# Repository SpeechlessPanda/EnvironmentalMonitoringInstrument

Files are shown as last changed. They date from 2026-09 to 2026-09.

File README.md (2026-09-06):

<div align="center">

# 环境监测仪

哈尔滨工业大学（深圳）电子工艺实习 · 题号 E1

**优秀项目** — 由任课教师评选的课程荣誉

手持环境监测仪：MSPM0G3507 采集气压、温湿度、光照，OLED 分页显示，超阈值蜂鸣器 / LED 报警，HC-05 把数据透传到浏览器面板。







<p>
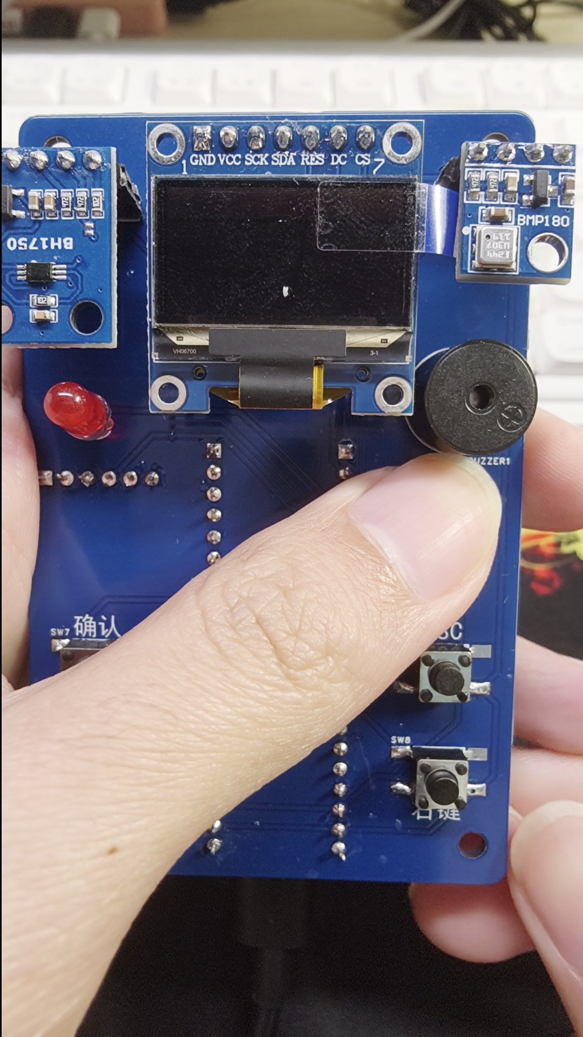
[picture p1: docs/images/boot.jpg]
开机
  
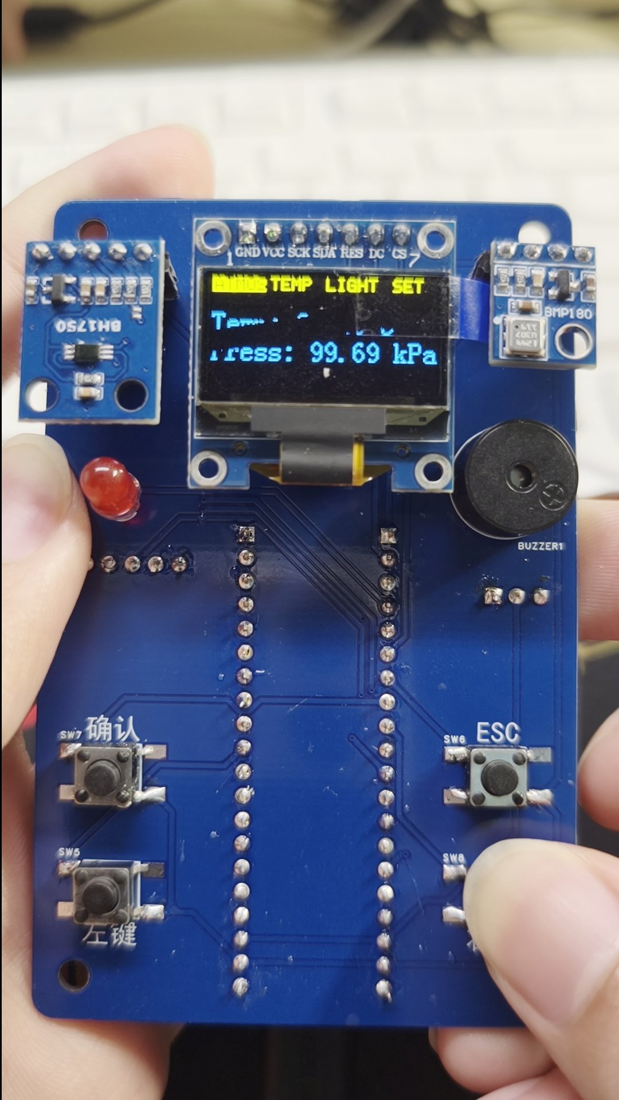
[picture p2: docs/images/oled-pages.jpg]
OLED 分页
  
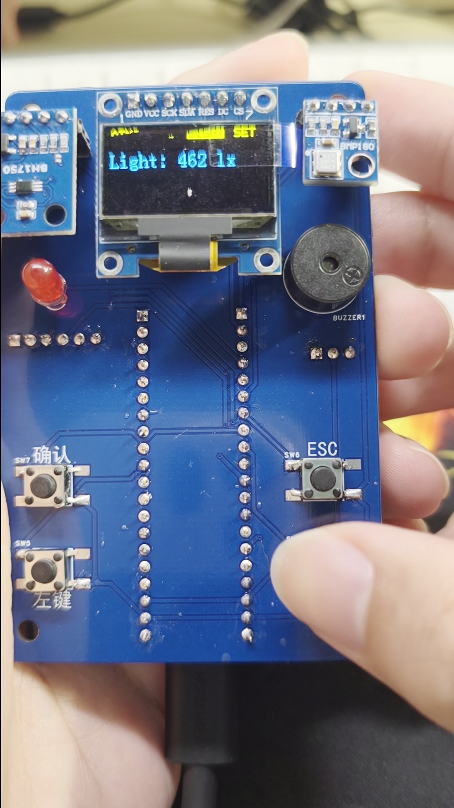
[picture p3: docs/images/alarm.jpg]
报警
  
</p>

</div>

## 优秀项目

本仓库是哈尔滨工业大学（深圳）电子工艺实习（题号 E1）选题下的作品，由**任课教师评选为优秀项目**。

## 功能

| 模块 | 器件 | 行为 |
| --- | --- | --- |
| 气压 / 温度 | BMP180 | ATMOS 页；BMP 温度 > 35 °C 报警 |
| 温湿度 | DHT11 | TEMP 页；温度 > 35 °C 或湿度 > 80 % 报警 |
| 光照 | BH1750 / GY-30 | LIGHT 页；< 50 lx 或 > 8000 lx 报警 |
| 显示 | 0.96" SSD1306 | 顶栏 ATMOS / TEMP / LIGHT / SET |
| 按键 | 左 / 右 / 确定 / 返回 | 翻页、进设置、改气压单位与报警方式 |
| 报警 | 蜂鸣器 PWM + LED | SET 页切换蜂鸣器或 LED |
| 无线 | HC-05 UART 9600 | 轮发 `BMP:` / `DHT:` / `LUX:` 文本 |

## 仓库结构

| 目录 | 内容 |
| --- | --- |
| [`firmware/`](firmware/) | MSPM0G3507 固件（Keil 主路径） |
| [`web/`](web/) | 单页 Web Bluetooth 面板 |
| [`hardware/`](hardware/) | EasyEDA Pro 工程、底板 BOM、外壳 3D 模型 |
| [`docs/`](docs/) | 使用说明、流程图、截图、功能 checklist |
| [`assets/`](assets/) | OLED 开机动画源图 |

## 固件

MCU：TI **MSPM0G3507**（Cortex-M0+，32 MHz，LQFP-64），配合地猛星 M0 底板与自制传感器盾板。

### 引脚

| 功能 | 引脚 |
| --- | --- |
| 软件 I2C SCL / SDA（BMP180 + BH1750） | PA0 / PA1 |
| DHT11 单总线 | PA9 |
| OLED 软件 SPI SCLK / MOSI / RES / DC / CS | PA12 / PA14 / PA21 / PA22 / PA2 |
| HC-05 UART3 TX / RX | PB2 / PB3 |
| HC-05 STATE | PA7 |
| 调试 UART0 TX / RX | PA10 / PA11 |
| 按键 LEFT / RIGHT / ENTER / ESC | PB8 / PB19 / PB20 / PB24 |
| LED | PA31 |
| 蜂鸣器 PWM TIMG0 | PA23 / PA13 |
| SWD | PA20 / PA19 |

### 编译（Keil）

1. 安装 [MSPM0 SDK 1.30.00.03](https://www.ti.com/tool/MSPM0-SDK) 与 Keil MDK + `MSPM0G1X0X_G3X0X` DFP。
2. 系统环境变量 `MSPM0_SDK_INSTALL_DIR` 指向 SDK 根目录。
3. 打开 `firmware/keil/empty_LP_MSPM0G3507_nortos_keil.uvprojx`，Build / Download。
4. 无工具链时可直接烧录 [`firmware/prebuilt/env-monitor.hex`](firmware/prebuilt/env-monitor.hex)。

不要手改 `firmware/ti_msp_dl_config.c` / `.h`。改引脚请编辑 `firmware/empty.syscfg` 后用 SysConfig 重新生成。

GCC / IAR / TIClang 目录是 SDK 空工程模板，**不会**链入 BSP，不能直接编出本项目镜像。

调试串口 UART0，9600 8N1。启动日志：`Board Init [[ ** LCKFB ** ]]`、`SYSTEM = READY`。

更细的构建说明见 [firmware/README.md](firmware/README.md)。

## 网页端

Chrome / Edge，HTTPS 或 `localhost`。先在系统蓝牙里配对名为 `HC-05` 的模块，打开 [`web/index.html`](web/index.html)，点「扫描并连接」。

固件走经典蓝牙 SPP；浏览器 Web Bluetooth 只能连 BLE GATT。模块必须是 BLE 透传（服务 `FFE0`、通知特征 `FFE1`），或另做 SPP ↔ BLE 桥。见 [docs/adr/0001-hc05-uart-telemetry.md](docs/adr/0001-hc05-uart-telemetry.md)。

协议与 `firmware/empty.c` 发送格式一致：

```
BMP:
Temp: 25.36 C
Press: 101.32 kPa
DHT:
Temp: 27 C
Humidty: 58 %
LUX:
Light: 123 lx
```

## 硬件

- [`hardware/PCB.eprj2`](hardware/PCB.eprj2)：EasyEDA Pro 工程（传感器盾板）
- [`hardware/BOM-shield.xlsx`](hardware/BOM-shield.xlsx)：底板焊料（蜂鸣器、按键、LED、排母）
- [`hardware/enclosure/`](hardware/enclosure/)：外壳 / 底座 / 按键 3mf（Bambu / Prusa 可直接切片）
- 传感器与蓝牙清单：[docs/parts.md](docs/parts.md)

## 使用

四键：左、右、确定、返回。左右翻页；任意页按返回回到 ATMOS；设置页确定进入编辑，再按确定改选项。完整说明：[docs/user-manual.md](docs/user-manual.md)（Word 原件 [`docs/user-manual.docx`](docs/user-manual.docx)）。

## 文档

| 文档 | 说明 |
| --- | --- |
| [docs/diagrams/](docs/diagrams/) | 主循环 / 传感器 / OLED 流程图 |
| [`docs/checklist.xlsx`](docs/checklist.xlsx) | 功能 checklist |
| [`docs/work-breakdown.xlsx`](docs/work-breakdown.xlsx) | 任务拆解 |
| [CONTEXT.md](CONTEXT.md) | 领域用语 |

## 团队

<div align="center">

| <a href="https://github.com/SpeechlessPanda">SpeechlessPanda</a> | <a href="https://github.com/mlove999">mlove999</a> | <a href="https://github.com/SnovvYT">SnovvYT</a> |
| :---: | :---: | :---: |
| **Mingjia Zhou** | **mlove999** | **SnovvYT** |
| [@SpeechlessPanda](https://github.com/SpeechlessPanda) | [@mlove999](https://github.com/mlove999) | [@SnovvYT](https://github.com/SnovvYT) |

</div>

## 许可

应用代码与文档：[MIT](LICENSE)。TI 启动文件与立创板级注释见 [NOTICE](NOTICE)。

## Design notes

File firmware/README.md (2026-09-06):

# Firmware

TI MSPM0G3507 nortos 超级循环。应用入口是仓库里的 `empty.c`（SDK 空工程留下的文件名，不是空程序）。

## 依赖

- MSPM0 SDK **1.30.00.03**
- Keil MDK-Lite 5.39 + ARMClang 6.21（实际编过的路径）
- Pack：`TexasInstruments.MSPM0G1X0X_G3X0X_DFP.1.3.1`
- 环境变量 `MSPM0_SDK_INSTALL_DIR`

DriverLib 静态库由 Keil 工程从 SDK 引用：

```
%MSPM0_SDK_INSTALL_DIR%\source\ti\driverlib\lib\keil\m0p\mspm0g1x0x_g3x0x\driverlib.a
```

预构建步骤调用 `%MSPM0_SDK_INSTALL_DIR%\tools\keil\syscfg.bat`。

## 源文件

| 文件 | 作用 |
| --- | --- |
| `empty.c` | 页面状态机、报警、HC-05 三段发送 |
| `empty.syscfg` | 引脚与外设，SysConfig 输入 |
| `ti_msp_dl_config.*` | SysConfig 输出，禁止手改 |
| `board.c` / `board.h` | 时钟、SysTick 延时、UART0 printf |
| `BSP/bsp_bmp180.*` | BMP180 + 软件 I2C |
| `BSP/bsp_gy30.*` | BH1750，复用上述 I2C |
| `BSP/dht11.*` | DHT11，约 1 s 读一次 |
| `BSP/OLED/` | SSD1306 软件 SPI、字库 |
| `BSP/bsp_key.*` | 四键 20 ms 消抖 |
| `BSP/bsp_bluetooth.*` | UART3 9600 发送 |
| `BSP/png.*` | 开机动画 `Showvideo()` |
| `prebuilt/env-monitor.hex` | 已验证镜像 |

## 主循环节拍

`delay_ms(10)`。DHT11 每 1 s；BMP180 与 BH1750 在同一条软件 I2C 上交替，间隔 200 ms。报警翻转 50 ms。透传每 100 ms 发一段，三轮一个周期。

## GCC / IAR / TIClang

这三个目录是 SDK 模板。它们的 makefile 只编 `empty.c`，没有 BSP，不能得到完整固件。留下来只为 SysConfig / 链接脚本参考。真要命令行构建，需要把 `BSP/*.c` 和 `BSP/OLED/oled.c` 加进 `OBJECTS`。

## 内存

Flash 128 KB，SRAM 32 KB。

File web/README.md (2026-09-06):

# BLE 传感器面板

单页 `index.html`。用 Web Bluetooth 订阅 BLE UART 通知，解析固件发出的 `BMP:` / `DHT:` / `LUX:` 文本。

## 运行

1. Chrome 或 Edge。
2. 用本地静态服务打开本目录（`localhost`）或 HTTPS。直接 `file://` 通常没有 Web Bluetooth。
3. 系统蓝牙先配对名为 `HC-05` 的模块。
4. 点击「扫描并连接蓝牙设备」。

## UUID

| 角色 | UUID |
| --- | --- |
| 服务 | `0000ffe0-0000-1000-8000-00805f9b34fb` |
| 通知特征 | `0000ffe1-0000-1000-8000-00805f9b34fb` |

只按广播名 `HC-05` 过滤，不绑定 MAC。若模块名不同，改 `EXPECTED_DEVICE_NAME`。

## 协议

与 `firmware/empty.c` 的 `sprintf` 一致。湿度字段拼写是固件里的 `Humidty`（缺 e），网页按这个匹配，不要“修正”正则除非同时改固件。

经典蓝牙 SPP 的 HC-05 **不能**被浏览器直连，见 `docs/adr/0001-hc05-uart-telemetry.md`。

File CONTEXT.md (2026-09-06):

# 环境监测仪

手持环境监测装置：MCU 周期采集三类传感器，在 OLED 上分页展示，超阈值报警，并把 ASCII 遥测经蓝牙透传到网页。

## Language

**环境监测仪**:
本仓库的产品。BMP180、DHT11、BH1750 加 OLED、按键、蜂鸣器、LED、HC-05。
_Avoid_: 气象站（内部笔记曾用，不是对外名称）

**页面**:
OLED 一次只显示一个 `Page_t`：`PAGE_BARO`（顶栏 ATMOS）、`PAGE_TEMP_HUMI`（TEMP）、`PAGE_LIGHT`（LIGHT）、`PAGE_SETTING`（SET）。
_Avoid_: 窗口, 菜单项（设置页里的选项叫设置项）

**设置项**:
设置页里当前高亮的可改字段。`set_item == 0` 气压单位，`set_item == 1` 报警方式（蜂鸣器 / LED）。
_Avoid_: 温度单位（源码旧注释，实际切的是报警方式）

**报警**:
当前页传感器越过阈值时，`alarm_flag` 置位，按 `alarm_mode` 驱动蜂鸣器或 LED。设置页不报警。
_Avoid_: 中断（报警在主循环里轮询，不是 NVIC 报警中断）

**透传**:
HC-05 把 MCU UART3 上的 ASCII 原样送到对端，固件不组 BLE GATT 包。
_Avoid_: 蓝牙协议栈, BLE 通知（那是网页端对 FFE1 的叫法）

**软件 I2C**:
`bsp_bmp180.c` 里 bit-bang 的 PA0/PA1 总线，BH1750 复用同一套起停字节函数。
_Avoid_: I2C0 外设（本工程没有用 MSPM0 硬件 I2C）

**盾板**:
插在地猛星 M0 底板排针上的自制传感器/按键/OLED 板，对应 `hardware/PCB.eprj2`。
_Avoid_: 底板（底板是地猛星 M0 模块本身）

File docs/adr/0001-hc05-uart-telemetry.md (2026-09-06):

# HC-05 UART 透传，网页走 BLE GATT

固件只把 ASCII 行写到 UART3。HC-05 在经典蓝牙上是 SPP 串口。浏览器 Web Bluetooth 只能连 BLE GATT，不能打开 SPP。

网页因此订阅常见 BLE 透传服务 `FFE0/FFE1`，并按设备名 `HC-05` 过滤。这要求实际用的模块是「BLE UART 透传」而不是纯经典 SPP；若只有经典 HC-05，需要额外的 SPP↔BLE 桥，网页无法直连。

没有在页面里写模块 MAC：MAC 是个人硬件标识，换一块板就会失效，也不该出现在公开仓库。

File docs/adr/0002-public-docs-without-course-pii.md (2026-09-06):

# 课程提交件不进公开 Git

课程 Word 说明书封面写了「仅供内部使用」和学校版权声明，正文含学号。演示 PPT 内嵌超过 100 MB 的视频，GitHub 普通 blob 放不进去。

公开仓库用 README、`docs/user-manual.md` 和流程图说明设计。原 Word/PPT/MP4/采购表留在被 gitignore 的 `_local/`，需要交作业时从本地取，不要 `git add`。

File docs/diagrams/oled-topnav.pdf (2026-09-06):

## OLED_Show_Top_Nav() 流程图

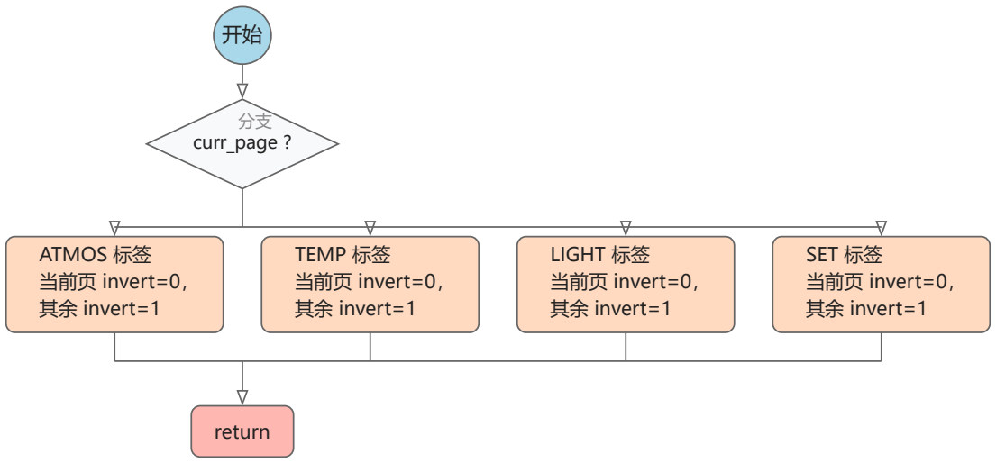
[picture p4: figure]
curr_page ?; ATMOS 标签 当前页 invert=0， 其余 invert=1; TEMP 标签 当前页 invert=0， 其余 invert=1; LIGHT 标签 当前页 invert=0， 其余 invert=1; SET 标签 当前页 invert=0， 其余 invert=1; return

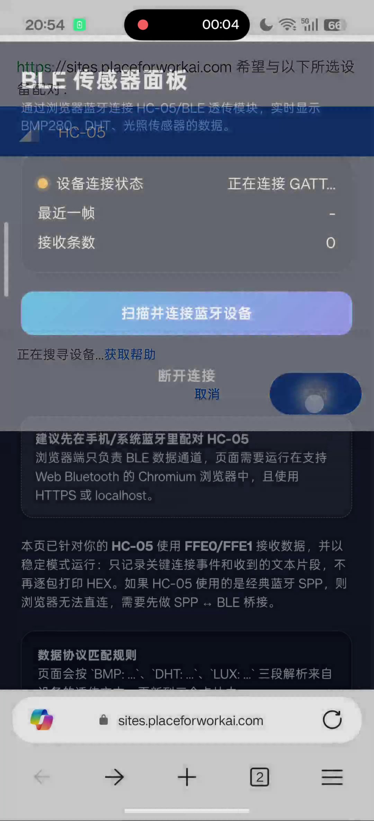
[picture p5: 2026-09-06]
docs/images/web-dashboard.jpg

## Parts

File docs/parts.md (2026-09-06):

# 物料

盾板焊料见 `hardware/BOM-shield.xlsx`。下面是传感器与模块，不含购买账号、学号或带追踪参数的购物链接。

| 物料 | 用途 | 备注 |
| --- | --- | --- |
| DHT11 | 温湿度 | 单总线 PA9 |
| BMP180 | 气压 / 温度 | 软件 I2C |
| BH1750（GY-30） | 光照 | 与 BMP180 共享 I2C |
| HC-05 | UART 透传 | UART3 9600 |
| 0.96" SSD1306 OLED | 显示 | 软件 SPI |
| 有源蜂鸣器 | 报警 | TIMG0 PWM |
| 轻触按键 ×4 | 导航 | PB8 / PB19 / PB20 / PB24 |
| 空气质量传感器 | — | 已采购，固件未使用 |

地猛星 M0（MSPM0G3507）底板为课程提供的核心板，不在本表。

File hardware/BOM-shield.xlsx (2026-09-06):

No. | Quantity | Comment | Designator | Footprint | Value | Manufacturer Part | Manufacturer | Supplier Part | Supplier | JLCPCB Price | LCSC Price
1 | 1 | 2.048kHz | BUZZER1 | BUZ-TH_BD12.0-P6.50-D0.6-FD | 2.048kHz | HC12085-16Ω-2048Hz-3.7MM | XHXDZ(兴华鑫) | C50387080 | LCSC | 0.61 | 0.6102
2 | 1 | PZ254V-11-07P | H1 | HDR-TH_7P-P2.54-V-M |  | PZ254V-11-07P | XFCN(兴飞) | C492406 | LCSC | 0.27 | 0.2703
3 | 1 | PZ254V-11-03P | H2 | HDR-TH_3P-P2.54-V-M_PZ254V-11-03P |  | PZ254V-11-03P | XFCN(兴飞) | C2937625 | LCSC | 0.12 | 0.1202
4 | 1 | PZ254V-11-04P | H3 | HDR-TH_4P-P2.54-V-M |  | PZ254V-11-04P | XFCN(兴飞) | C2691448 | LCSC | 0.164 | 0.1641
5 | 1 | PZ254V-11-05P | H4 | HDR-TH_5P-P2.54-V-M |  | PZ254V-11-05P | XFCN(兴飞) | C492404 | LCSC | 0.201 | 0.2009
6 | 1 | PZ254V-11-06P | H5 | HDR-TH_6P-P2.54-V-M |  | PZ254V-11-06P | XFCN(兴飞) | C492405 | LCSC | 0.262 | 0.2617
7 | 1 | 3A2RUD | LED1 | LED-TH_BD3.5-P2.28_3A2RUC |  | 3A2RUD | Guiguang light(桂光光电) | C52034637 | LCSC | 0.117 | 0.117
8 | 4 | M3螺丝 | SCREW1,SCREW2,SCREW3,SCREW4 | M3螺丝
9 | 4 | KH-6X6X5H-STM | SW5,SW6,SW7,SW8 | SW-SMD_4P-L6.0-W6.0-P4.50-LS9.0_H5.0 |  | KH-6X6X5H-STM | kinghelm(金航标) | C2837531 | LCSC | 0.115 | 0.1153
10 | 2 | KH-2.54FH-1X20P-H8.5 | U1,U2 | HDR-TH_20P-P2.54-V-F-2 |  | KH-2.54FH-1X20P-H8.5 | kinghelm(金航标) | C2905423 | LCSC | 1.408 | 1.4076

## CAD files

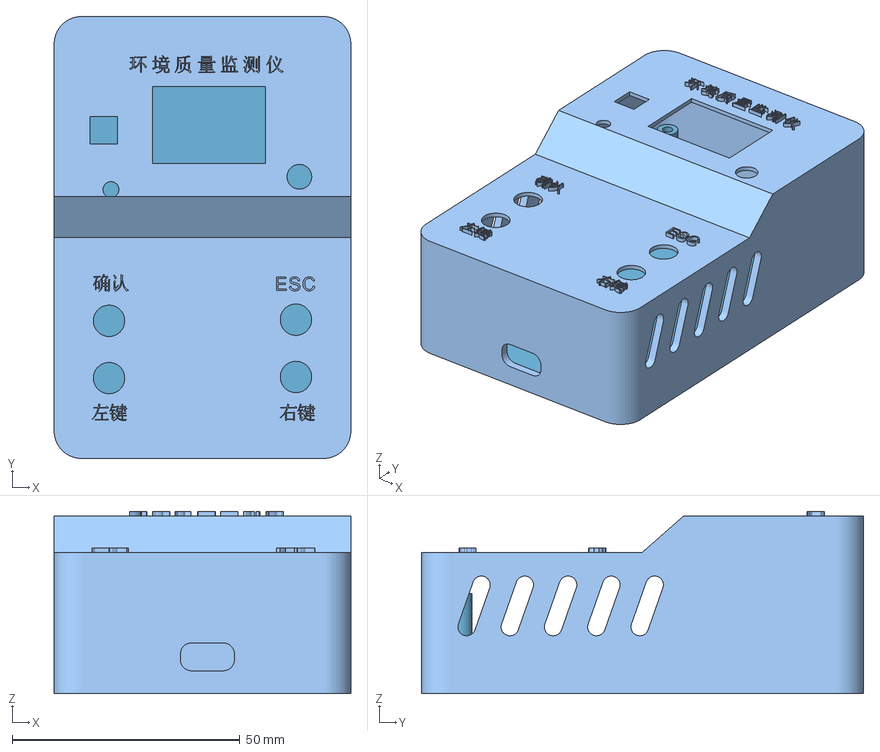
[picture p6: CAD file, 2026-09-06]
hardware/enclosure/shell.3mf
65.1 x 97.0 x 40.0 mm
实体40
实体47

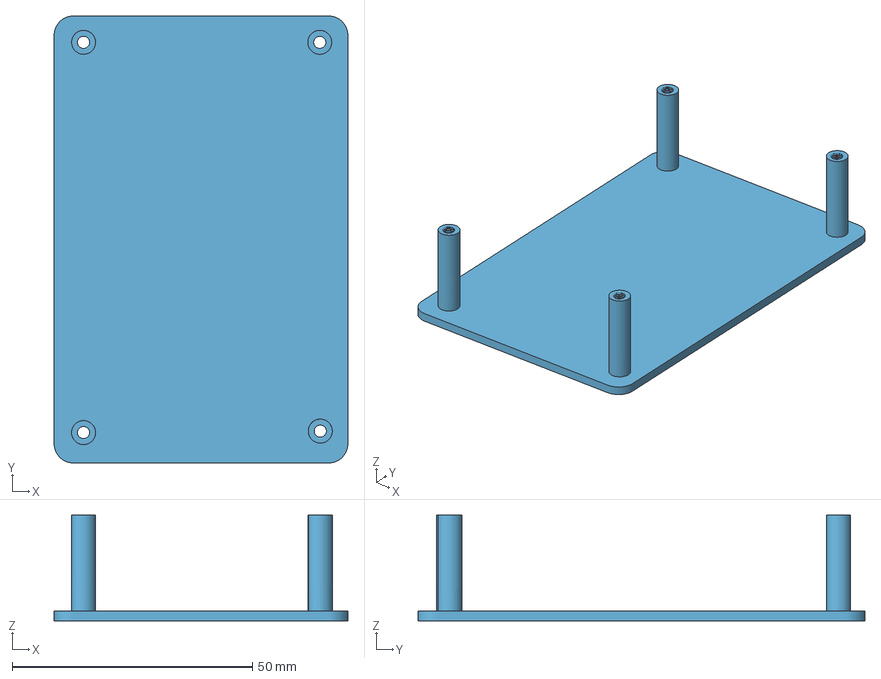
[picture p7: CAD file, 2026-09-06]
hardware/enclosure/base.3mf
61.1 x 93.0 x 22.0 mm

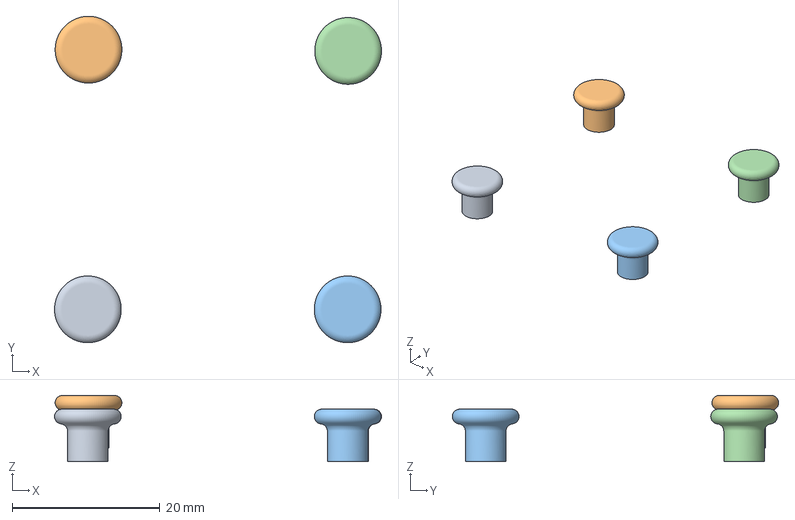
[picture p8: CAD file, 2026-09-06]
hardware/enclosure/button.3mf
44.3 x 44.2 x 8.96 mm
实体1
实体6
实体7
实体8

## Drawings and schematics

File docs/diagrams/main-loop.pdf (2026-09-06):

## MSP0 气象站 main() 主流程图

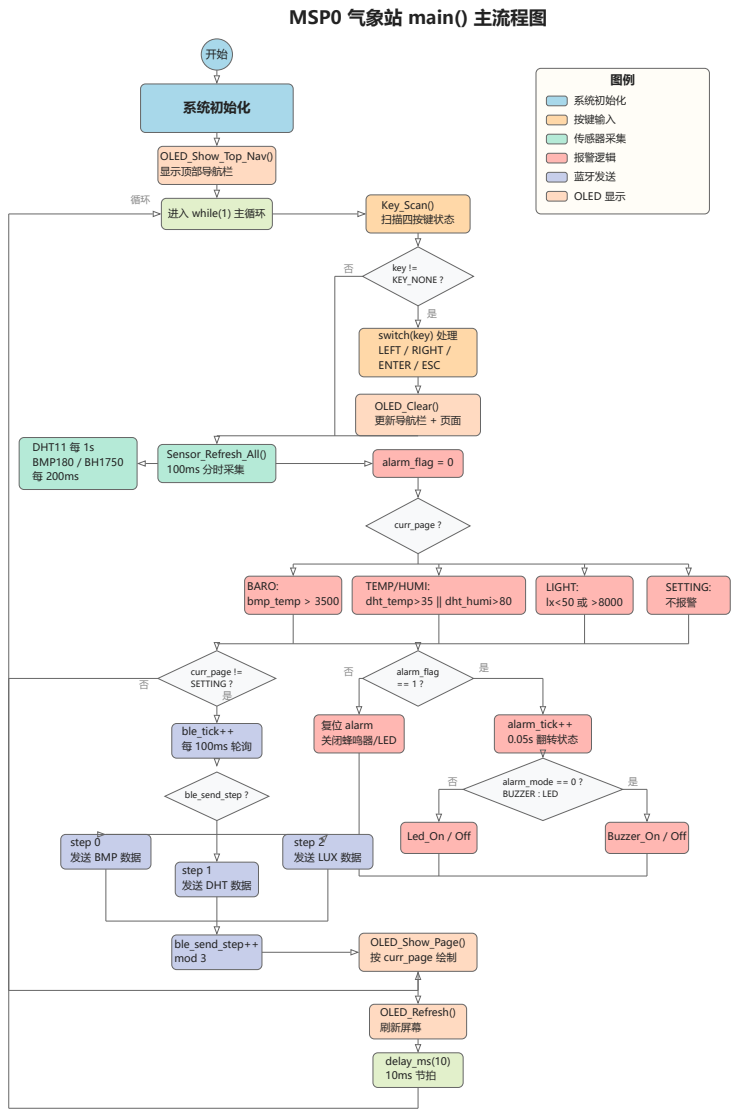
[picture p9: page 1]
系统初始化; OLED_Show_Top_Nav() 显示顶部导航栏; 进入 while(1) 主循环; Key_Scan(); 扫描四按键状态; key != KEY_NONE ?; OLED_Clear() 更新导航栏 + 页面; Sensor_Refresh_All() 100ms 分时采集; DHT11 每 1s BMP180 / BH1750 每 200ms; alarm_flag = 0; curr_page ?; BARO: bmp_temp > 3500; TEMP/HUMI: dht_temp>35 || dht_humi>80; LIGHT: lx<50 或 >8000; SETTING: 不报警; alarm_flag == 1 ?; alarm_tick++ 0.05s 翻转状态; alarm_mode == 0 ? BUZZER : LED; Led_On / Off; Buzzer_On / Off; 复位 alarm 关闭蜂鸣器/LED; curr_page !=; SETTING ?; ble_tick++ 每 100ms 轮询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

switch(key) 处理
LEFT / RIGHT /
ENTER / ESC

step 0
发送 BMP 数据

step 2
发送 LUX 数据

step 1
发送 DHT 数据

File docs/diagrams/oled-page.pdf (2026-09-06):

## OLED_Show_Page() 流程图

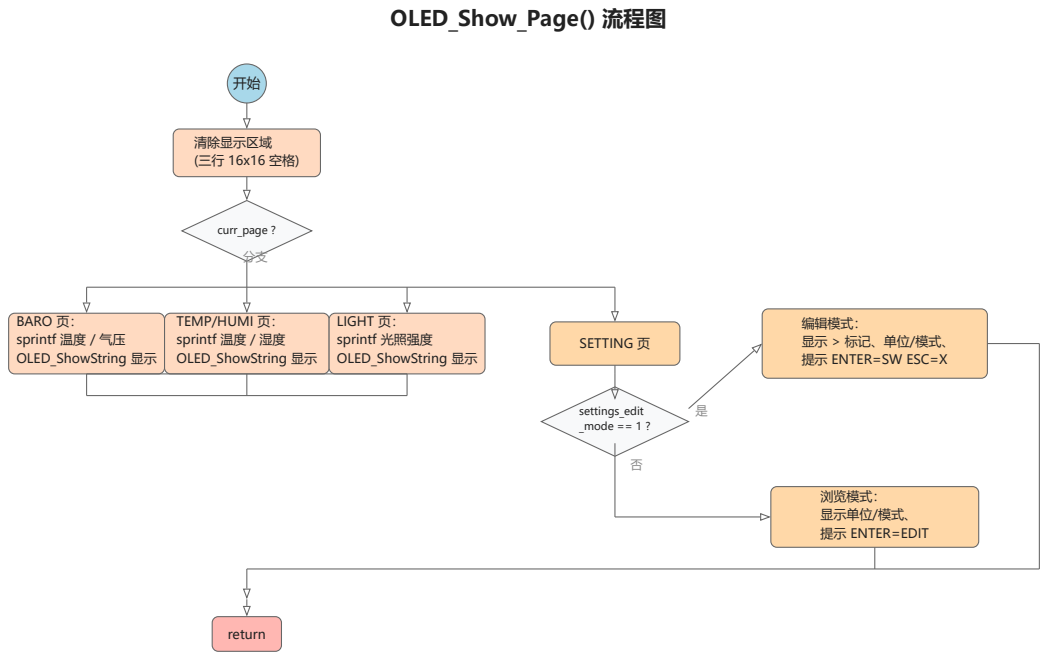
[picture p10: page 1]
清除显示区域 (三行 16x16 空格); curr_page ?; LIGHT 页： sprintf 光照强度 OLED_ShowString 显示; SETTING 页; settings_edit _mode == 1 ?; return

BARO 页：
sprintf 温度 / 气压
OLED_ShowString 显示

TEMP/HUMI 页：
sprintf 温度 / 湿度

编辑模式：
提示 ENTER=SW ESC=X

浏览模式：
显示单位/模式、
提示 ENTER=EDIT

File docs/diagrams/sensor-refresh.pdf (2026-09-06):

## Sensor_Refresh_All() 流程图

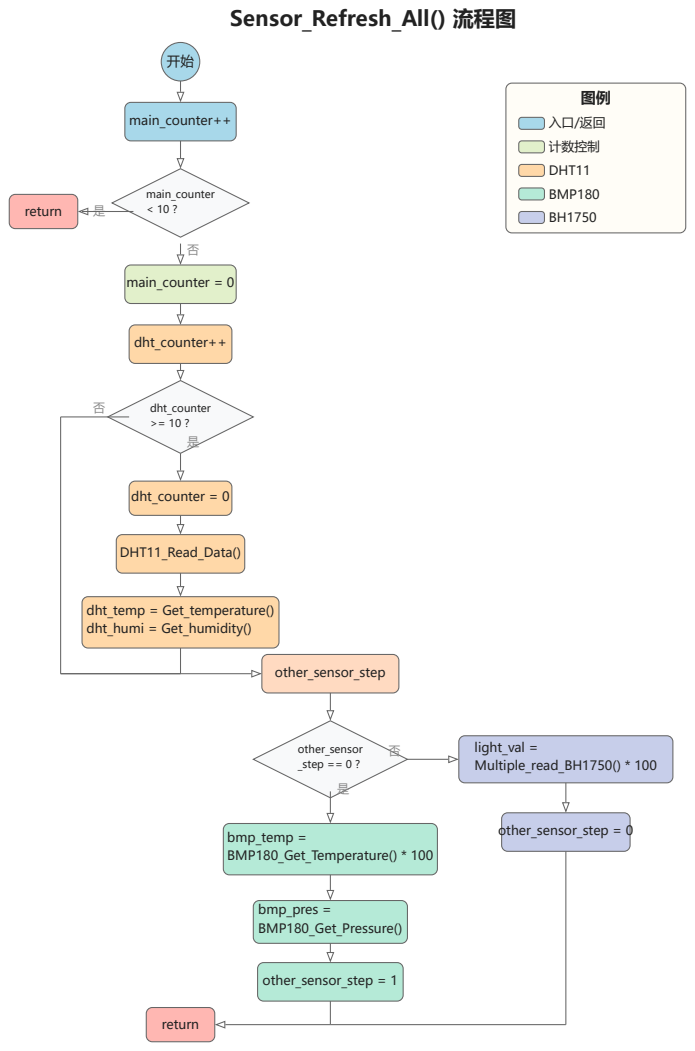
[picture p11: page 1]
main_counter++; main_counter; return; main_counter = 0; dht_counter++; dht_counter >= 10 ? 是; dht_counter = 0; DHT11_Read_Data(); dht_temp = Get_temperature() dht_humi = Get_humidity(); other_sensor_step; other_sensor _step == 0 ?; bmp_temp = BMP180_Get_Temperature() * 100; bmp_pres = BMP180_Get_Pressure(); other_sensor_step = 1; light_val = Multiple_read_BH1750() * 100; other_sensor_step = 0; 计数控制; DHT11; BMP180

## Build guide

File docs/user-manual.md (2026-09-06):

# 环境监测仪使用说明

四枚按键：左键、右键、确定键、返回键。

## 传感器界面

左右键切换页面。任意界面按返回键回到 ATMOS（气压）页。

## 设置界面

按确定进入设置编辑。编辑模式下左右键选择设置项，再按确定更改该项。按返回退出编辑，留在设置页。

设置项：

1. 气压单位
2. 报警方式（蜂鸣器 / LED）

## 报警

- 气压页：BMP180 温度高于 35 °C
- 温湿度页：DHT11 温度高于 35 °C，或湿度高于 80 %
- 光照页：低于 50 lx 或高于 8000 lx
- 设置页：不报警

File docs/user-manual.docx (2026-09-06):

环境检测仪使用说明书

四枚按键：左键 右键 确定键 返回键

传感器界面：左键 右键可以进行页面切换。任意界面按下ESC键可一键返回ATMOS界面

设置界面：按下ENTER键进入设置模式，ESC可退出设置模式。设计模式按下左右键可进行设置选项的选择，ENTER键可进行设置选项的更改。

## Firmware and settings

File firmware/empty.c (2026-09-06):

#include "board.h"
#include <stdio.h>
#include <string.h>
#include "bsp_bmp180.h"
#include "oled.h"
#include "DHT11.h"
#include "bsp_gy30.h"
#include "ti_msp_dl_config.h"
#include "bsp_key.h"
#include "bsp_bluetooth.h"
#include "ti_msp_dl_config.h"
#include "png.h"
      
typedef enum {
    PAGE_BARO = 0,
    PAGE_TEMP_HUMI,
    PAGE_LIGHT,
    PAGE_SETTING
} Page_t;

Page_t curr_page = PAGE_BARO;
volatile uint8_t pres_unit = 0;
volatile uint8_t alarm_mode = 0;
uint8_t set_item = 0;           // 当前选中的设置项（0=气压单位，1=温度单位）
uint8_t settings_edit_mode = 0; // 0=浏览模式（左右键切页面） 1=编辑模式（左右键选设置项）

uint32_t bmp_temp, bmp_pres;
int dht_temp, dht_humi;
uint32_t light_val;
char disp_buf[32];

char disp_buff[128];
uint32_t ble_tick = 0; // 蓝牙发送定时
uint8_t ble_send_step = 0;

Page_t last_page = PAGE_BARO; // 保存进入设置前的页面

volatile uint8_t  alarm_flag = 0;      // 报警标志 1=报警中 0=关闭
uint32_t alarm_tick = 0;            // 报警计时（非阻塞用）
uint8_t  alarm_state = 0;           // 报警状态 1=响/亮 0=停

void Sensor_Refresh_All(void);
void OLED_Show_Top_Nav(void);
void OLED_Show_Page(void);
void Buzzer_On(void);   // 蜂鸣器开启
void Buzzer_Off(void);  // 蜂鸣器关闭
void Led_On(void);
void Led_Off(void);

int main(void)
{
    board_init();
		// PWM初始化，默认关闭蜂鸣器
		SYSCFG_DL_init();
		DL_TimerG_startCounter(PWM_BUZZER_INST);
    Buzzer_Off();
		Led_Off();
	
    // 手动关闭UART0接收中断，避免board_init()中的配置干扰
    DL_UART_Main_disableInterrupt(UART_0_INST, DL_UART_MAIN_INTERRUPT_RX);
    NVIC_DisableIRQ(UART_0_INST_INT_IRQN);
    NVIC_ClearPendingIRQ(UART_0_INST_INT_IRQN);
	
    delay_ms(1000); // 等待系统稳定
    printf("SYSTEM = READY\r\n");
    // 等待传输完成，确保串口输出稳定
    while(DL_UART_isBusy(UART_0_INST));
	
    OLED_Init();
    OLED_Clear();
    OLED_ShowString(0, 16, (uint8_t *)"  SYSTEM READY", 16, 1);
    OLED_Refresh();
    delay_ms(1000);
		OLED_Clear();
		Showvideo();
    OLED_Clear();
    Key_Init();
    delay_ms(100);
    // 初始化所有传感器
    delay_ms(1000); // DHT11上电稳定时间
    BMP180_Get_param();
    delay_ms(100);
    GY30_Init();
    delay_ms(100);
		Bluetooth_Init();
    OLED_Show_Top_Nav();
    OLED_Refresh();
    while(1)
    {
        Key_State key = Key_Scan();

        if(key != KEY_NONE)
        {
            switch(key)
            {
                /* ---- 左键 ---- */
                case KEY_LEFT_PRESSED:
                    if (curr_page == PAGE_SETTING && settings_edit_mode)
                    {
                        /* 编辑模式：切换上一个设置项 */
                        set_item = (set_item - 1 + 2) % 2;
                    }
                    else
                    {
                        /* 浏览模式：切换上一个页面（首尾循环） */
                        settings_edit_mode = 0; // 离开设置页时退出编辑模式
                        if (curr_page == PAGE_BARO)
                            curr_page = PAGE_SETTING;
                        else
                            curr_page = curr_page - 1;
                    }
                    break;

                /* ---- 右键 ---- */
                case KEY_RIGHT_PRESSED:
										
                    if (curr_page == PAGE_SETTING && settings_edit_mode)
                    {
                        /* 编辑模式：切换下一个设置项 */
                        set_item = (set_item + 1) % 2;
                    }
                    else
                    {
                        /* 浏览模式：切换下一个页面（首尾循环） */
                        settings_edit_mode = 0; // 离开设置页时退出编辑模式
                        curr_page = (curr_page + 1) % 4;
                    }
                    break;

                /* ---- ENTER键 ---- */
                case KEY_ENTER_PRESSED:
                    if (curr_page == PAGE_SETTING && settings_edit_mode)
                    {
                        /* 编辑模式：切换单位 */
                        if (set_item == 0)
													{
                            pres_unit = !pres_unit;
													}
                        else if (set_item == 1)
												{
														alarm_mode = !alarm_mode;
												}
                    }
                    else if (curr_page == PAGE_SETTING && !settings_edit_mode)
                    {
                        /* 浏览模式下在设置页：进入编辑模式 */
                        settings_edit_mode = 1;
                        set_item = 0;
                    }
                    else
                    {
                        /* 其他页面：跳转到设置页（浏览模式） */
                        last_page = curr_page;
                        curr_page = PAGE_SETTING;
                        settings_edit_mode = 0;
                        set_item = 0;
                    }
                    break;

                /* ---- ESC键 ---- */
                case KEY_ESC_PRESSED:
                    if (curr_page == PAGE_SETTING && settings_edit_mode)
                    {
                        /* 编辑模式：退出编辑，回到浏览模式（留在设置页） */
                        settings_edit_mode = 0;
                    }
                    else
                    {
                        /* 浏览模式：返回首页 */
                        settings_edit_mode = 0;
                        curr_page = PAGE_BARO;
                    }
                    break;

                default: break;
            }

            // 页面切换时更新显示
            OLED_Clear();
            OLED_Show_Top_Nav();
						OLED_Show_Page();
            OLED_Refresh();
        }

        // 传感器数据刷新
        Sensor_Refresh_All();

				alarm_flag = 0; // 默认关闭报警
        switch(curr_page)
        {
            case PAGE_BARO:
                // 气压页：仅判断 BMP温度 > 35℃ 报警
                if(bmp_temp > 3500) alarm_flag = 1;
                break;

            case PAGE_TEMP_HUMI:
                // 温湿度页：DHT温度>35℃ OR 湿度>80% 报警
                if(dht_temp > 35 || dht_humi > 80) alarm_flag = 1;
                break;

            case PAGE_LIGHT:
                // 光强页：<50 lx OR >8000 lx 报警
                if( (light_val/100 < 50) || (light_val/100 > 8000) ) alarm_flag = 1;
                break;

            case PAGE_SETTING:
                // 设置页：不报警
                alarm_flag = 0;
                break;
        }

// ===================== 统一报警执行逻辑（响1s 停1s） =====================
        if(alarm_flag == 1)
        {
            alarm_tick++;
            if(alarm_tick >= 5) // 10ms×5 = 0.05秒
            {
                alarm_tick = 0;
                alarm_state = !alarm_state;
                if(alarm_mode == 0)
                {
										// 蜂鸣器报警
                    alarm_state ? Buzzer_On() : Buzzer_Off();
                }
                else
                {
                    // LED报警
                     alarm_state ? Led_On() : Led_Off();
                }
            }
        }
        else
        {
            // 报警关闭：复位 + 关闭蜂鸣器
            alarm_tick = 0;
            alarm_state = 0;
            Buzzer_Off();
						Led_Off();
        }
				// ===================== 3段式蓝牙发送（标题不拆分，无阻塞） =====================
				if(curr_page != PAGE_SETTING)
				{
						ble_tick++;
						if(ble_tick >= 10) 
						{
								ble_tick = 0;
								// 分3次发送，标题完整不拆分
								switch(ble_send_step)
								{
										case 0:
												// 第1段：BMP 完整数据（标题+温度+气压）
												sprintf(disp_buff,"BMP:\nTemp: %d.%02d C\nPress: %d.%02d kPa\n",
																bmp_temp/100, bmp_temp%100,
																bmp_pres/1000, (bmp_pres%1000)/10);
												BLE_send_String((uint8_t *)disp_buff);
												break;
										case 1:
												// 第2段：DHT 完整数据（标题+温度+湿度）
												sprintf(disp_buff,"DHT:\nTemp: %d C\nHumidty: %d %%\n",
																dht_temp, dht_humi);
												BLE_send_String((uint8_t *)disp_buff);
												break;
										case 2:
												// 第3段：LUX 完整数据（标题+光照）
												sprintf(disp_buff,"LUX:\nLight: %d lx\n",
																light_val/100);
												BLE_send_String((uint8_t *)disp_buff);
												break;
								}
								// 循环 0→1→2→0
								ble_send_step = (ble_send_step + 1) % 3;
						}
				}
        // 显示页面
        OLED_Show_Page();
        OLED_Refresh();

        delay_ms(10);
    }
}

// 传感器刷新函数
void Sensor_Refresh_All(void)
{
    static uint16_t main_counter = 0;
    static uint16_t dht_counter = 0;
    static uint8_t other_sensor_step = 0;

    main_counter++;
    if (main_counter < 10) // 每100ms执行一次
    {
        return;
    }
    main_counter = 0;
    dht_counter++;

    // DHT11每1秒读取一次
    if (dht_counter >= 10)
    {
        dht_counter = 0;
        unsigned int dht_result = DHT11_Read_Data();
        dht_temp = (int)Get_temperature();
        dht_humi = (int)Get_humidity();
    }

    // 其他传感器分时采集，不影响DHT11
    switch(other_sensor_step)
    {
        case 0:
            // 大气压传感器（每200ms更新一次）
            bmp_temp = BMP180_Get_Temperature() * 100;
            bmp_pres = BMP180_Get_Pressure();
            other_sensor_step = 1;
            break;

        case 1:
            // 光强传感器（每200ms更新一次）
            light_val = (uint32_t)(Multiple_read_BH1750() * 100);
            other_sensor_step = 0;
            break;
    }
}

void OLED_Show_Top_Nav(void)
{
    OLED_ShowString(0,   0, (uint8_t *)"ATMOS",  8, (curr_page==0)?0:1);
    OLED_ShowString(32,  0, (uint8_t *)"TEMP",    8, (curr_page==1)?0:1);
    OLED_ShowString(64,  0, (uint8_t *)"LIGHT",   8, (curr_page==2)?0:1);
    OLED_ShowString(96,  0, (uint8_t *)" SET",     8, (curr_page==3)?0:1);
}

void OLED_Show_Page(void)
{
    // 清除显示区域
    OLED_ShowString(0, 16, (uint8_t *)"                ", 16, 1);
    OLED_ShowString(0, 32, (uint8_t *)"                ", 16, 1);
    OLED_ShowString(0, 48, (uint8_t *)"                ", 16, 1);

    switch(curr_page)
    {
        case PAGE_BARO:
            // 大气压页面显示
						sprintf(disp_buf, "Temp: %d.%02d C", bmp_temp/100, bmp_temp%100);
						OLED_ShowString(0, 16, (uint8_t *)disp_buf, 16, 1);
				
            if(pres_unit == 0)
                sprintf(disp_buf, "Press: %d.%02d kPa", bmp_pres/1000, (bmp_pres%1000)/10);
            else
            {
                uint32_t atm_int = bmp_pres / 101325;
                uint32_t atm_dec = (bmp_pres % 101325) * 100 / 101325;
                sprintf(disp_buf, "Press: %d.%02d atm", atm_int, atm_dec);
            }
            OLED_ShowString(0, 32, (uint8_t *)disp_buf, 16, 1);
            break;

        case PAGE_TEMP_HUMI:
            // 温湿度页面显示
            sprintf(disp_buf, "Temp: %d C", dht_temp);
            OLED_ShowString(0, 16, (uint8_t *)disp_buf, 16, 1);
						
            sprintf(disp_buf, "Humidty: %d %%", dht_humi);
            OLED_ShowString(0, 32, (uint8_t *)disp_buf, 16, 1);
            break;

        case PAGE_LIGHT:
            // 光强页面显示
            sprintf(disp_buf, "Light: %d lx", light_val/100);
            OLED_ShowString(0, 16, (uint8_t *)disp_buf, 16, 1);
            break;

        case PAGE_SETTING:
            if(settings_edit_mode)
            {
                /* 编辑模式：显示>标记，ENTER切换单位，ESC退出 */
                sprintf(disp_buf, "%cPress: %s",
                        (set_item==0)?'>':' ', pres_unit?"atm":"kPa");
                OLED_ShowString(0, 16, (uint8_t *)disp_buf, 16, 1);

                sprintf(disp_buf, "%cMode: %s", 
												(set_item==1)?'>':' ', alarm_mode?"LED":"BUZZER");
                OLED_ShowString(0, 32, (uint8_t *)disp_buf, 16, 1);
                OLED_ShowString(0, 48, (uint8_t *)"ENTER=SW ESC=X", 16, 1);
            }
            else
            {
                /* 浏览模式：无标记，提示按ENTER进入编辑 */
                sprintf(disp_buf, " Press: %s", pres_unit?"atm":"kPa");
                OLED_ShowString(0, 16, (uint8_t *)disp_buf, 16, 1);

                sprintf(disp_buf, " Mode: %s", alarm_mode?"LED":"BUZZER");
                OLED_ShowString(0, 32, (uint8_t *)disp_buf, 16, 1);

                OLED_ShowString(0, 48, (uint8_t *)"ENTER=EDIT", 16, 1);
            }
            break;
    }
}
void Buzzer_On(void)
{
    // 开启PWM定时器 + 设置占空比发声
    DL_TimerG_startCounter(PWM_BUZZER_INST);
    DL_TimerG_setCaptureCompareValue(PWM_BUZZER_INST, 2500, GPIO_PWM_BUZZER_C1_IDX);
}

void Buzzer_Off(void)
{
    // 1. 占空比设为0
    DL_TimerG_setCaptureCompareValue(PWM_BUZZER_INST, 0, GPIO_PWM_BUZZER_C1_IDX);
    // 2. 停止PWM定时器
    DL_TimerG_stopCounter(PWM_BUZZER_INST);
    // 3. 强制拉低引脚
    DL_GPIO_clearPins(GPIO_PWM_BUZZER_C1_PORT, GPIO_PWM_BUZZER_C1_PIN);
}
void Led_On(void){DL_GPIO_setPins(GPIO_LED_PORT, GPIO_LED_PA31_PIN);}
void Led_Off(void){DL_GPIO_clearPins(GPIO_LED_PORT, GPIO_LED_PA31_PIN);}

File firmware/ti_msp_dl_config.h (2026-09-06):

/*
 * Copyright (c) 2023, Texas Instruments Incorporated - http://www.ti.com
 * All rights reserved.
 *
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
 * *  Redistributions of source code must retain the above copyright
 *    notice, this list of conditions and the following disclaimer.
 *
 * *  Redistributions in binary form must reproduce the above copyright
 *    notice, this list of conditions and the following disclaimer in the
 *    documentation and/or other materials provided with the distribution.
 *
 * *  Neither the name of Texas Instruments Incorporated nor the names of
 *    its contributors may be used to endorse or promote products derived
 *    from this software without specific prior written permission.
 *
 * THIS SOFTWARE IS PROVIDED BY THE COPYRIGHT HOLDERS AND CONTRIBUTORS "AS IS"
 * AND ANY EXPRESS OR IMPLIED WARRANTIES, INCLUDING, BUT NOT LIMITED TO,
 * THE IMPLIED WARRANTIES OF MERCHANTABILITY AND FITNESS FOR A PARTICULAR
 * PURPOSE ARE DISCLAIMED. IN NO EVENT SHALL THE COPYRIGHT OWNER OR
 * CONTRIBUTORS BE LIABLE FOR ANY DIRECT, INDIRECT, INCIDENTAL, SPECIAL,
 * EXEMPLARY, OR CONSEQUENTIAL DAMAGES (INCLUDING, BUT NOT LIMITED TO,
 * PROCUREMENT OF SUBSTITUTE GOODS OR SERVICES; LOSS OF USE, DATA, OR PROFITS;
 * OR BUSINESS INTERRUPTION) HOWEVER CAUSED AND ON ANY THEORY OF LIABILITY,
 * WHETHER IN CONTRACT, STRICT LIABILITY, OR TORT (INCLUDING NEGLIGENCE OR
 * OTHERWISE) ARISING IN ANY WAY OUT OF THE USE OF THIS SOFTWARE,
 * EVEN IF ADVISED OF THE POSSIBILITY OF SUCH DAMAGE.
 */

/*
 *  ============ ti_msp_dl_config.h =============
 *  Configured MSPM0 DriverLib module declarations
 *
 *  DO NOT EDIT - This file is generated for the MSPM0G350X
 *  by the SysConfig tool.
 */
#ifndef ti_msp_dl_config_h
#define ti_msp_dl_config_h

#define CONFIG_MSPM0G350X

#if defined(__ti_version__) || defined(__TI_COMPILER_VERSION__)
#define SYSCONFIG_WEAK __attribute__((weak))
#elif defined(__IAR_SYSTEMS_ICC__)
#define SYSCONFIG_WEAK __weak
#elif defined(__GNUC__)
#define SYSCONFIG_WEAK __attribute__((weak))
#endif

#include <ti/devices/msp/msp.h>
#include <ti/driverlib/driverlib.h>
#include <ti/driverlib/m0p/dl_core.h>

#ifdef __cplusplus
extern "C" {
#endif

/*
 *  ======== SYSCFG_DL_init ========
 *  Perform all required MSP DL initialization
 *
 *  This function should be called once at a point before any use of
 *  MSP DL.
 */


/* clang-format off */

#define POWER_STARTUP_DELAY                                                (16)



#define CPUCLK_FREQ                                                     32000000



/* Defines for PWM_BUZZER */
#define PWM_BUZZER_INST                                                    TIMG0
#define PWM_BUZZER_INST_IRQHandler                              TIMG0_IRQHandler
#define PWM_BUZZER_INST_INT_IRQN                                (TIMG0_INT_IRQn)
#define PWM_BUZZER_INST_CLK_FREQ                                         4000000
/* GPIO defines for channel 0 */
#define GPIO_PWM_BUZZER_C0_PORT                                            GPIOA
#define GPIO_PWM_BUZZER_C0_PIN                                    DL_GPIO_PIN_23
#define GPIO_PWM_BUZZER_C0_IOMUX                                 (IOMUX_PINCM53)
#define GPIO_PWM_BUZZER_C0_IOMUX_FUNC                IOMUX_PINCM53_PF_TIMG0_CCP0
#define GPIO_PWM_BUZZER_C0_IDX                               DL_TIMER_CC_0_INDEX
/* GPIO defines for channel 1 */
#define GPIO_PWM_BUZZER_C1_PORT                                            GPIOA
#define GPIO_PWM_BUZZER_C1_PIN                                    DL_GPIO_PIN_13
#define GPIO_PWM_BUZZER_C1_IOMUX                                 (IOMUX_PINCM35)
#define GPIO_PWM_BUZZER_C1_IOMUX_FUNC                IOMUX_PINCM35_PF_TIMG0_CCP1
#define GPIO_PWM_BUZZER_C1_IDX                               DL_TIMER_CC_1_INDEX
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

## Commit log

2026-09-06 chore: sanitize repo layout for public GitHub
    Keep a single firmware tree, the Web Bluetooth dashboard, and hardware
    sources. Drop duplicate dumps, unlicensed Windows tools, build artifacts,
    personal names, class labels, and Office author metadata. Point Keil at
    MSPM0_SDK_INSTALL_DIR.
    [BOM-shield.xlsx, checklist.xlsx, work-breakdown.xlsx]
2026-09-06 feat: add enclosure 3D models
    Place the shell, base, and button 3mf under hardware/enclosure, and
    drop the student-id prefix from the filenames.
    [base.3mf, button.3mf, shell.3mf]
2026-09-06 docs: drop web screenshot and highlight teacher honor
    Remove the BLE dashboard photo from the web section. Call out
    that this E1 project was selected as 优秀项目 by course faculty.

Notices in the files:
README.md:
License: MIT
